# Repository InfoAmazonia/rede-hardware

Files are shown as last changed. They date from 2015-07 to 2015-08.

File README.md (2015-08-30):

# Mãe d'Água - Hardware

An open hardware to monitor water quality in real time. The system will help infer physicochemical properties and variables that differentiate drinkable from contaminated water. Mãe d'Água is part of the project <a href="http://infoamazonia.org/projects/infoamazonia-network/">InfoAmazonia Network</a>.

The device will measure acidity in water by potential of hydrogen (pH), oxidation - reduction potential (ORP), conductivity, temperature and barometric pressure in the water level, which are important factors to consider when assessing water quality for human consumption.

The hardware is modular:
- Module 1 (M1): composed by Arduino Mega, it is responsible for all processing of information captured by the sensors and the entire power supply (connected to an external source).
- Module 2 (M2): Arduino shield (in this repository), designed using Eagle platform, with the barometric pressure sensor and connectors for coupling the pH, ORP, conductivity and water temperature sensors. This way, it is possible to select modules that are appropriate aiming the best cost-benefit ratio of specific desired application.
- Module 3 (M3): responsible for mobile communication (2G), capable of transmitting data by Internet and by SMS to the InfoAmazonia Network internet server. As auxiliary data access strategy, the M2 also features a SD memory card slot.

The complete hardware will capture a reading of each of the sensors per hour, and send them to our remote server, which will provide visualization in an open database.

The development files of the project's hardware/software can be found at:
- Hardware's design: https://github.com/InfoAmazonia/rede-hardware
- Firmware: https://github.com/InfoAmazonia/rede-firmware
- Website for data visualization: https://github.com/InfoAmazonia/rede-site
- SMS backend (to receive data from the equipments and to send alerts to the communities): https://github.com/InfoAmazonia/rede-sms

This hardware is licensed under the <a href="http://www.ohwr.org/attachments/2388/cern_ohl_v_1_2.txt">CERN Open Hardware License Version 1.2.</a>

The EC sensor of this project is based on <a href="http://publiclab.org/notes/donblair/09-30-2014/coqui-bbv1-0">Coqui BBv1.0.</a>

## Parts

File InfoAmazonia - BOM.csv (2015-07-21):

Qty | Value | Device | Package | Parts | Description | MF | MPN | OC_FARNELL | OC_NEWARK | PROD_ID
1 | 100 | R-EU_R0603 | R0603 | R3 | RESISTOR, European symbol
22 | 100nF | C-EUC0603 | C0603 | C1, C6, C9, C10, C11, C13, C14, C15, C16, C17, C18, C20, C21, C22, C24, C25, C27, C29, C31, C33, C35, C37 | CAPACITOR, European symbol
1 | 10100660686 | USD-SOCKETNEW | MICRO-SD-SOCKET-PP | U3 | microSD Socket
3 | 10k | R-EU_R0603 | R0603 | R1, R2, R5 | RESISTOR, European symbol
7 | 10uF | C-EUC0603 | C0603 | C19, C23, C26, C32, C34, C36, C38 | CAPACITOR, European symbol
1 | 1k | R-EU_R0603 | R0603 | R8 | RESISTOR, European symbol
1 | 1uF | C-EUC0603 | C0603 | C30 | CAPACITOR, European symbol
1 | 2.2nF | C-EUC0603 | C0603 | C28 | CAPACITOR, European symbol
1 | 220 | R-EU_R0603 | R0603 | R4 | RESISTOR, European symbol
3 | 220uF | CPOL-EUUD6,3-5,8 | UD-6,3X5,8_NICHICON | C7, C8, C12 | POLARIZED CAPACITOR, European symbol
1 | 2k2 | R-EU_R0603 | R0603 | R11 | RESISTOR, European symbol
4 | 30k | R-EU_R0603 | R0603 | R7, R12, R13, R15 | RESISTOR, European symbol
3 | 31-5431-10RFX | BNCPTH | BNC | J1, J2, J3 | BNC Connector, Mouser Part# 5227161
2 | 47uF | CPOL-EUSMC_B | SMC_B | C2, C3 | POLARIZED CAPACITOR, European symbol
2 | 47uF | CPOL-EUUD6,3-5,8 | UD-6,3X5,8_NICHICON | C4, C5 | POLARIZED CAPACITOR, European symbol
1 | 4M7 | R-EU_R0603 | R0603 | R6 | RESISTOR, European symbol
1 | 5k | RTRIM329W | RTRIM3296W | R10 | Trimm resistor
3 | 74HC4053D | 4053D | SO16 | IC6, IC7, IC8 | Triple 2-channel ANALOG MULTIPLEXER
2 | 75k | R-EU_R0603 | R0603 | R9, R14 | RESISTOR, European symbol
4 | 89400-0420 | M04JST-PTH-VERT | JST-4-PTH-VERT | JP1, JP2, JP3, JP4 | Header 4
1 | ADAFRUIT FONA | ADAFRUIT_FONA | ADAFRUIT_FONA | IC1
1 | ALS-PT19 | LIGHTSENSORALS | ALS-PT19 | U4 | Ambient Light Sensor |  |  |  |  | IC-11836
1 | ARDUINO-MEGAPRO | ARDUINO-MEGAPRO | ARDUINO_MEGA_2560 | U1 | Arduino Mega board footprint
1 | CA3140AM Z | AMPOP | SO8 | IC12 | High Performance Video Op Amp | ALTERA CORPORATION | AD811JRZ | 9426485 | 82H2980
1 | CD4050BD | 4050D | SO16 | IC5 | Hex non-inverting BUFFER
1 | HEF4051BT | 4051D | SO16 | IC3 | 8-channel ANALOG MULTIPLEXER
6 | INFO-AMAZONIA-MODULE | INFO-AMAZONIA-MODULE | INFO-AMAZONIA-MODULE | MD1, MD2, MD3, MD4, MD5, MD6
1 | LM2662 | LM2662 | SO8 | IC2
1 | MIC29302AWD | MIC29XXX | TO252-5 | IC4
1 | MPL3115A2 | MPL3115A2LGA8 | LGA8 | U2 | Altimeter/Pressure Sensor, I2C, 1.95V-3.6V supply, 50 to 110kPa |  |  |  |  | IC-10869
1 | NE555 | NE555 | SO8 | IC11 | General purpose bipolar Timer
1 | SHT20 | SHT2X | SHT2X | IC9
1 | TL032C | AMPOP_2R | SO8 | IC10 | Dual Precision, Low Cost, High Speed BiFET Op Amp | ALTERA CORPORATION | AD712KRZ | 1263975 | 59K4556
1 | TL081BCDG4 | AMPOP | SO8 | IC13 | High Performance Video Op Amp | ALTERA CORPORATION | AD811JRZ | 9426485 | 82H2980

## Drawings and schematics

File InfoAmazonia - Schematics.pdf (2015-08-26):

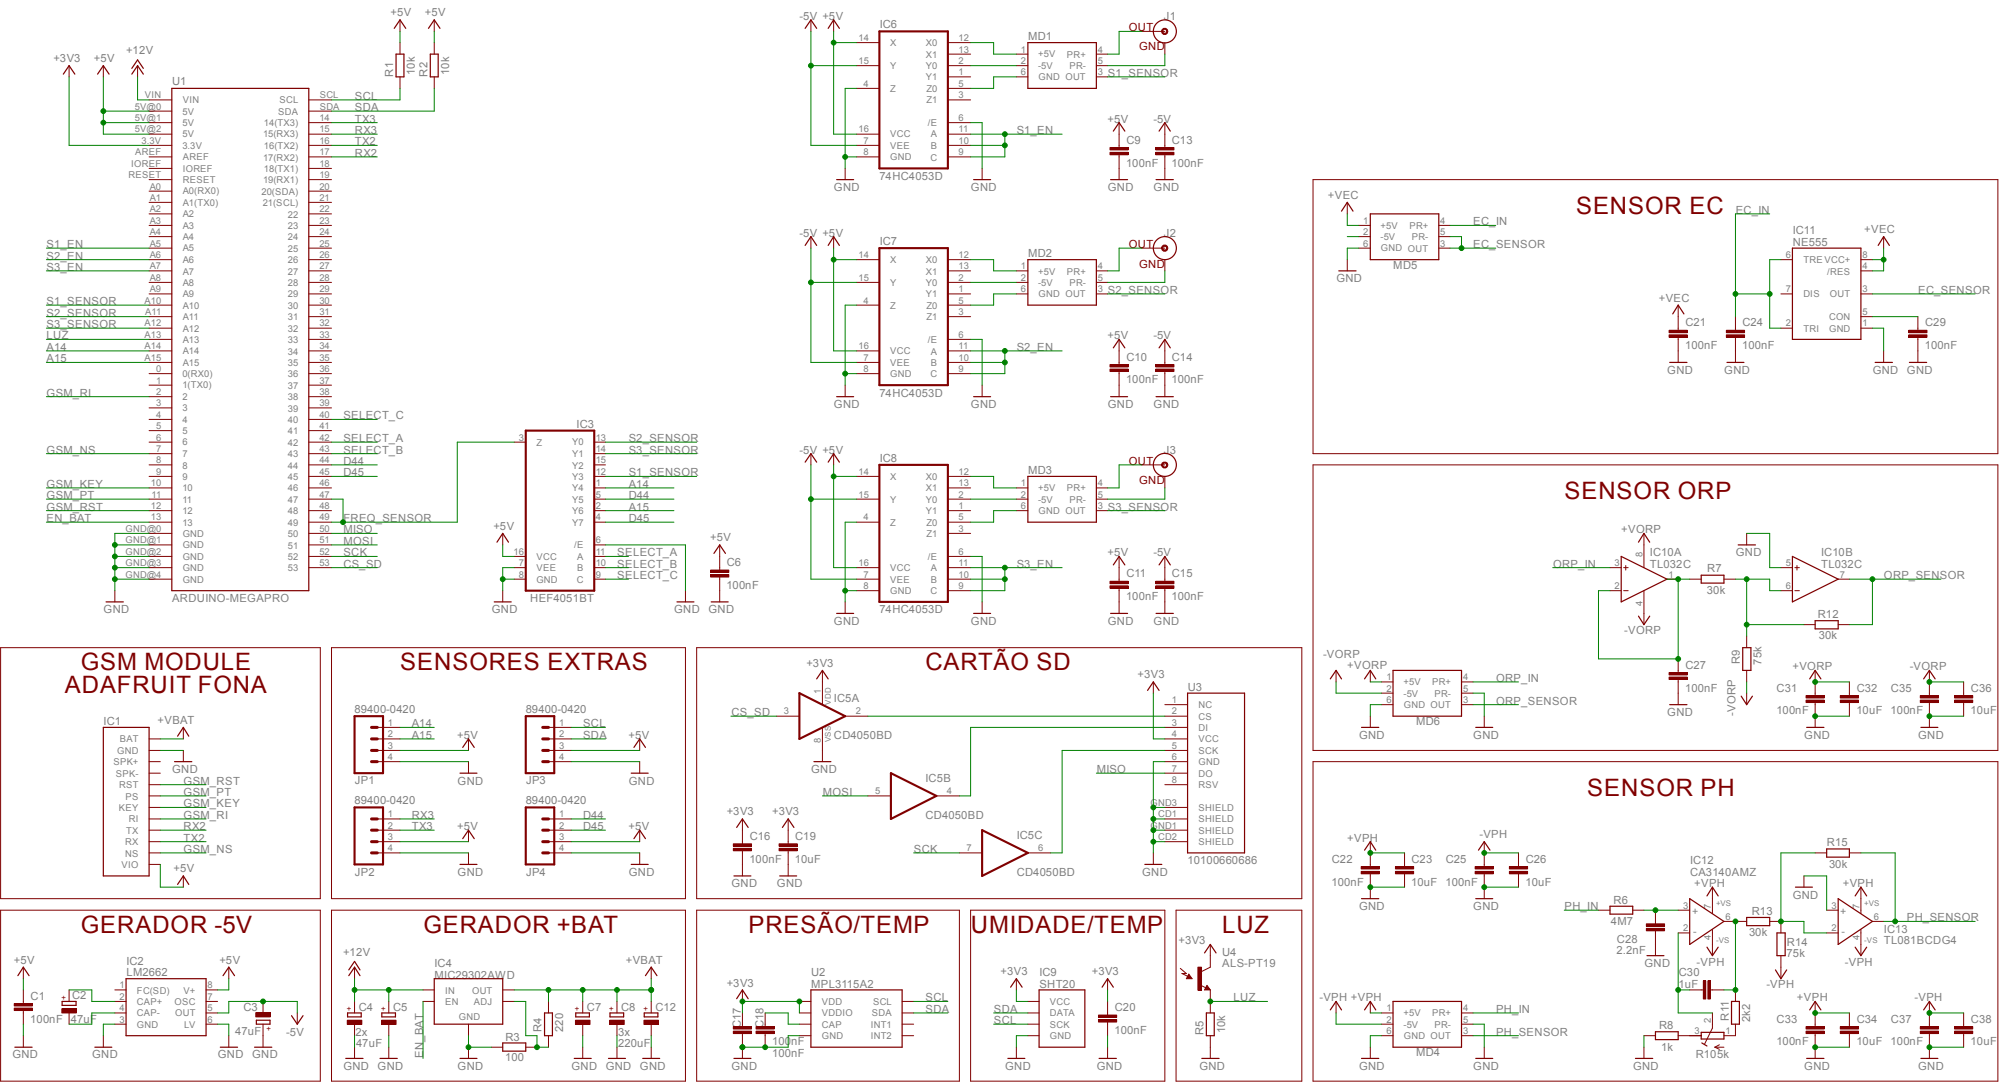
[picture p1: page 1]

5V 5V@1 | TX3
5V 5V@2 | RX3

GND GND@1 | MOSI
GND GND@2 | SCK

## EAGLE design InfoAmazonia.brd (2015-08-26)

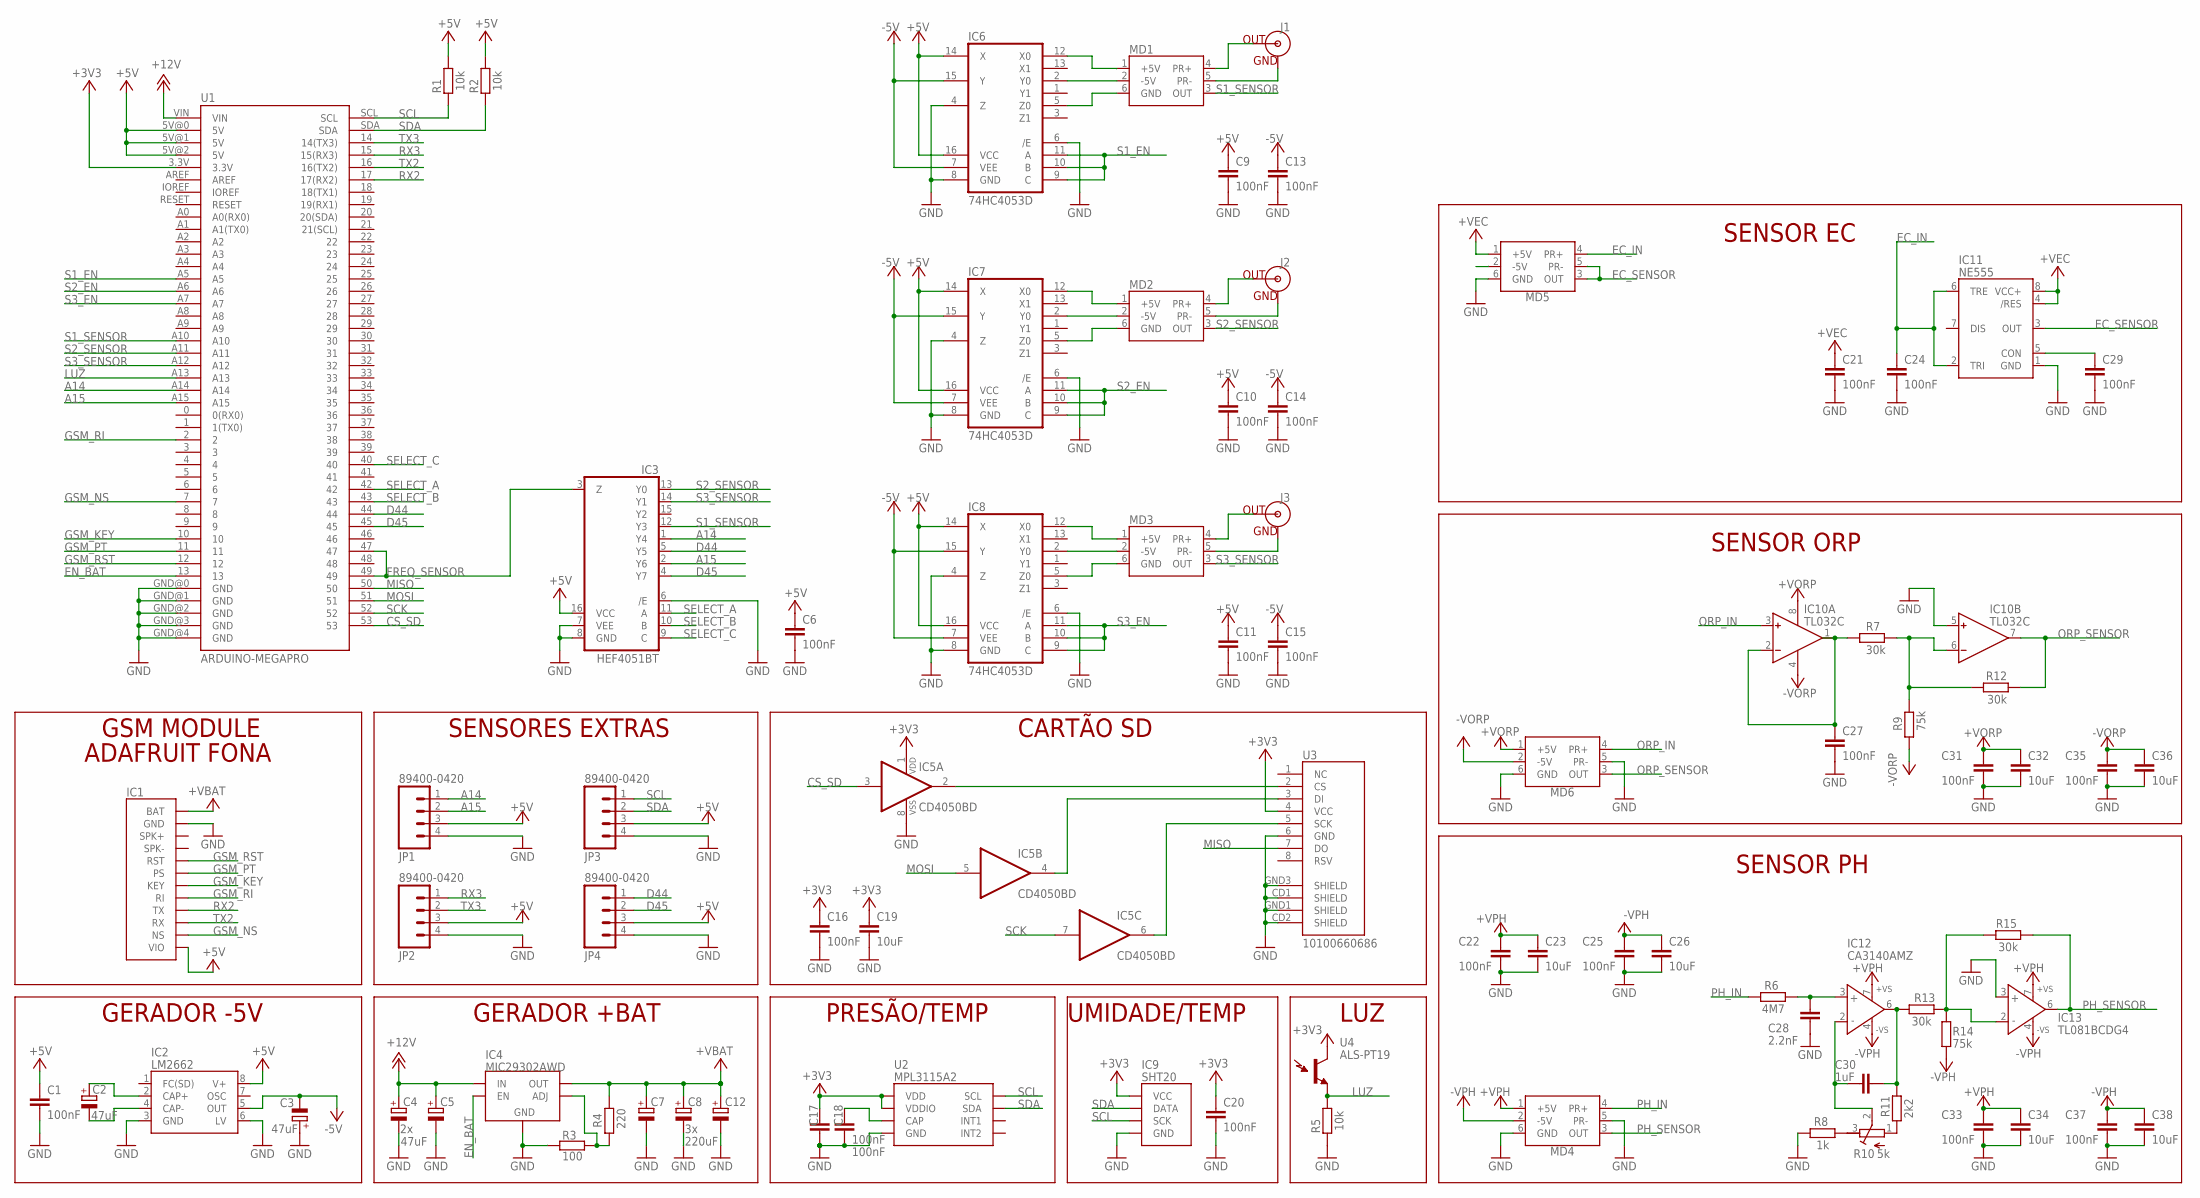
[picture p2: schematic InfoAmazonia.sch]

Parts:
C1, C6, C9, C10, C11, C13, C14, C15, C16, C17, C18, C20, C21, C22, C24, C25, C27, C29, C31, C33, C35, C37: 100nF; C0603
C2, C3: 47uF; SMC_B
C4, C5: 47uF; UD-6,3X5,8_NICHICON
C7, C8, C12: 220uF; UD-6,3X5,8_NICHICON
C19, C23, C26, C32, C34, C36, C38: 10uF; C0603
C28: 2.2nF; C0603
C30: 1uF; C0603
IC1: ADAFRUIT FONA; ADAFRUIT_FONA
IC2: LM2662; SO8
IC3: HEF4051BT; SO16
IC4: MIC29302AWD; TO252-5
IC5: CD4050BD; SO16
IC6, IC7, IC8: 74HC4053D; SO16
IC9: SHT20; SHT2X
IC10: TL032C; SO8
IC11: NE555; SO8
IC12: CA3140AMZ; SO8
IC13: TL081BCDG4; SO8
J1, J2, J3: 31-5431-10RFX; BNC
JP1, JP2, JP3, JP4: 89400-0420; JST-4-PTH-VERT
MD1, MD2, MD3, MD4, MD5, MD6: INFO-AMAZONIA-MODULE
R1, R2, R5: 10k; R0603
R3: 100; R0603
R4: 220; R0603
R6: 4M7; R0603
R7, R12, R13, R15: 30k; R0603
R8: 1k; R0603
R9, R14: 75k; R0603
R10: 5k; RTRIM3296W
R11: 2k2; R0603
U1: ARDUINO-MEGAPRO; ARDUINO_MEGA_2560
U2: MPL3115A2; LGA8
U3: 10100660686; MICRO-SD-SOCKET-PP
U4: ALS-PT19

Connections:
+3V3: C16.1, C17.1, C19.1, C20.1, IC5.1 (VDD), IC9.5 (VCC), U1.3.3V, U2.1 (VDD), U2.4 (VDDIO), U3.4 (VCC), U4.C (C1)
+5V: C1.1, C6.1, C9.1, C10.1, C11.1, IC1.12 (VIO), IC2.8 (V+), IC3.16 (VCC), IC6.14 (X), IC6.16 (VCC), IC7.14 (X), IC7.16 (VCC), IC8.14 (X), IC8.16 (VCC), JP1.3, JP2.3, JP3.3, JP4.3, R1.2, R2.2, U1.5V@0 (5V), U1.5V@1 (5V), U1.5V@2 (5V)
+12V: C4.+, C5.+, IC4.2 (IN), U1.VIN
+VBAT: C7.+, C8.+, C12.+, IC1.1 (BAT), IC4.4 (OUT), R4.1
+VEC: C21.1, IC11.4 (/RES), IC11.8 (VCC+), MD5.1 (+5V)
+VORP: C31.1, C32.1, IC10.8 (V+), MD6.1 (+5V)
+VPH: C22.1, C23.1, C33.1, C34.1, IC12.7 (+VS), IC13.7 (+VS), MD4.1 (+5V)
-5V: C3.-, C13.1, C14.1, C15.1, IC2.5 (OUT), IC6.7 (VEE), IC6.15 (Y), IC7.7 (VEE), IC7.15 (Y), IC8.7 (VEE), IC8.15 (Y)
-VORP: C35.1, C36.1, IC10.4 (V-), MD6.2 (-5V), R9.2
-VPH: C25.1, C26.1, C37.1, C38.1, IC12.4 (-VS), IC13.4 (-VS), MD4.2 (-5V), R14.2
A14: IC3.1 (Y4), JP1.1, U1.A14
A15: IC3.2 (Y6), JP1.2, U1.A15
CS_SD: IC5.3 (I), U1.53
D44: IC3.5 (Y5), JP4.1, U1.44
D45: IC3.4 (Y7), JP4.2, U1.45
EC_IN: C24.1, IC11.2 (TRI), IC11.6 (TRE), MD5.4 (PR+)
EC_SENSOR: IC11.3 (OUT), MD5.3 (OUT), MD5.5 (PR-)
EN_BAT: IC4.1 (EN), U1.13
FC(SD): IC2.1 (FC(SD))
FREQ_SENSOR: IC3.3 (Z), U1.47, U1.49
GND: C1.2, C3.+, C4.-, C5.-, C6.2, C7.-, C8.-, C9.2, C10.2, C11.2, C12.-, C13.2, C14.2, C15.2, C16.2, C17.2, C18.2, C19.2, C20.2, C21.2, C22.2, C23.2, C24.2, C25.2, C26.2, C27.2, C28.2, C29.2, C31.2, C32.2, C33.2, C34.2, C35.2, C36.2, C37.2, C38.2, IC1.2 (GND), IC1.K1 (GND), IC1.K2 (GND), IC2.3 (GND), IC2.6 (LV), IC3.6 (/E), IC3.7 (VEE), IC3.8 (GND), IC4.3 (GND), IC4.6 (GND), IC5.8 (VSS), IC6.4 (Z), IC6.6 (/E), IC6.8 (GND), IC7.4 (Z), IC7.6 (/E), IC7.8 (GND), IC8.4 (Z), IC8.6 (/E), IC8.8 (GND), IC9.2 (GND), IC9.7 (GND), IC10.5 (IN+), IC11.1 (GND), IC13.3 (IN+), JP1.4, JP2.4, JP3.4, JP4.4, MD4.5 (PR-), MD4.6 (GND), MD5.6 (GND), MD6.5 (PR-), MD6.6 (GND), R3.1, R5.1, R8.2, U1.GND@0 (GND), U1.GND@1 (GND), U1.GND@2 (GND), U1.GND@3 (GND), U1.GND@4 (GND), U2.3 (GND), U3.6 (GND), U3.CD1 (SHIELD), U3.CD2 (SHIELD), U3.GND1 (SHIELD), U3.GND3 (SHIELD)
GSM_KEY: IC1.7 (KEY), U1.10
GSM_NS: IC1.11 (NS), U1.7
GSM_PT: IC1.6 (PS), U1.11
GSM_RI: IC1.8 (RI), U1.2
GSM_RST: IC1.5 (RST), U1.12
LUZ: R5.2, U1.A13, U4.E (E1)
MISO: U1.50, U3.7 (DO)
MOSI: IC5.5 (I), U1.51
unnamed: J1.GND, MD1.5 (PR-)
unnamed: C28.1, IC12.3 (IN+), R6.2
unnamed: C30.1, IC12.2 (IN-), R10.2 (S)
unnamed: C30.2, IC12.6 (OUT), R11.2, R13.2
unnamed: IC13.2 (IN-), R13.1, R14.1, R15.1
unnamed: R8.1, R10.3 (E)
unnamed: C18.1, U2.2 (CAP)
unnamed: R10.1 (A), R11.1
unnamed: J1.S (OUT), MD1.4 (PR+)
unnamed: C29.1, IC11.5 (CON)
unnamed: J2.GND, MD2.5 (PR-)
unnamed: J2.S (OUT), MD2.4 (PR+)
unnamed: J3.GND, MD3.5 (PR-)
unnamed: C2.-, IC2.4 (CAP-)
unnamed: C27.1, IC10.1 (OUT), IC10.2 (IN-), R7.2
unnamed: C2.+, IC2.2 (CAP+)
unnamed: IC10.6 (IN-), R7.1, R9.1, R12.1
unnamed: IC4.5 (ADJ), R3.2, R4.2
unnamed: IC5.6 (O), U3.5 (SCK)
unnamed: IC5.4 (O), U3.3 (DI)
unnamed: IC5.2 (O), U3.2 (CS)
unnamed: J3.S (OUT), MD3.4 (PR+)
unnamed: IC6.12 (X0), MD1.1 (+5V)
unnamed: IC6.2 (Y0), MD1.2 (-5V)
unnamed: IC6.5 (Z0), MD1.6 (GND)
unnamed: IC7.5 (Z0), MD2.6 (GND)
unnamed: IC7.2 (Y0), MD2.2 (-5V)
unnamed: IC7.12 (X0), MD2.1 (+5V)
unnamed: IC8.12 (X0), MD3.1 (+5V)
unnamed: IC8.2 (Y0), MD3.2 (-5V)
unnamed: IC8.5 (Z0), MD3.6 (GND)
ORP_IN: IC10.3 (IN+), MD6.4 (PR+)
ORP_SENSOR: IC10.7 (OUT), MD6.3 (OUT), R12.2
PH_IN: MD4.4 (PR+), R6.1
PH_SENSOR: IC13.6 (OUT), MD4.3 (OUT), R15.2
RX2: IC1.9 (TX), U1.17 (17(RX2))
RX3: JP2.1, U1.15 (15(RX3))
S1_EN: IC6.9 (C), IC6.10 (B), IC6.11 (A), U1.A5
S1_SENSOR: IC3.12 (Y3), MD1.3 (OUT), U1.A10
S2_EN: IC7.9 (C), IC7.10 (B), IC7.11 (A), U1.A6
S2_SENSOR: IC3.13 (Y0), MD2.3 (OUT), U1.A11
S3_EN: IC8.9 (C), IC8.10 (B), IC8.11 (A), U1.A7
S3_SENSOR: IC3.14 (Y1), MD3.3 (OUT), U1.A12
SCK: IC5.7 (I), U1.52
SCL: IC9.6 (SCK), JP3.1, R1.1, U1.SCL, U2.8 (SCL)
SDA: IC9.1 (DATA), JP3.2, R2.1, U1.SDA, U2.7 (SDA)
SELECT_A: IC3.11 (A), U1.42
SELECT_B: IC3.10 (B), U1.43
SELECT_C: IC3.9 (C), U1.40
TX2: IC1.10 (RX), U1.16 (16(TX2))
TX3: JP2.2, U1.14 (14(TX3))

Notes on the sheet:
SENSOR ORP
SENSOR PH
PRESÃO/TEMP
UMIDADE/TEMP
GERADOR -5V
GERADOR +BAT
LUZ
CARTÃO SD
SENSOR EC
GSM MODULE
ADAFRUIT FONA
SENSORES EXTRAS

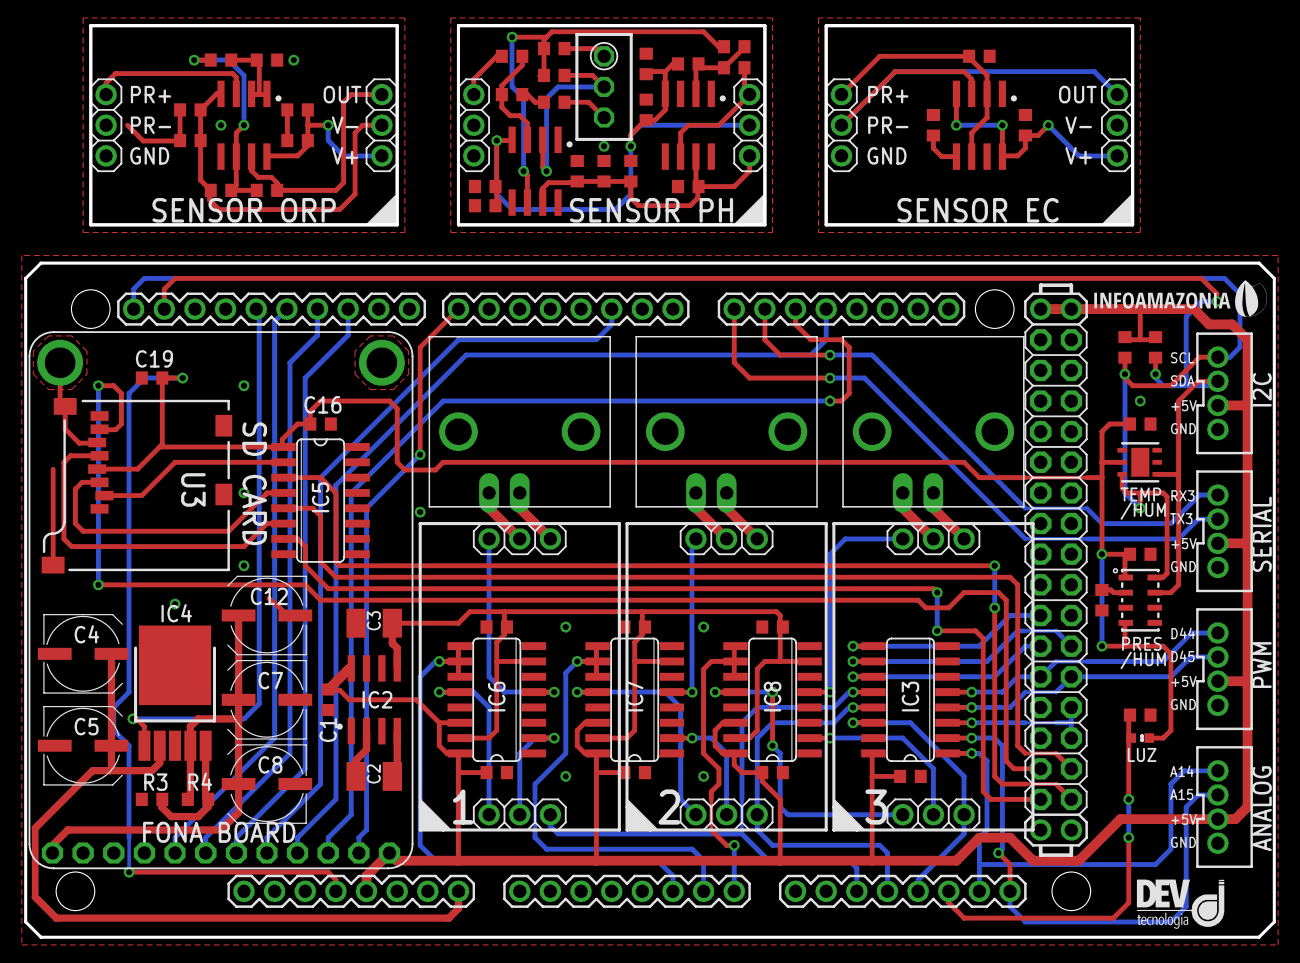
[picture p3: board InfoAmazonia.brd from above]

Board: 2 copper layers, 103.5 x 75.6 mm, 85 parts (0 on the bottom side), 79 nets.

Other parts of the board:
U$1: LOGO-INFO-0.38
U$2: LOGO-DEV-0.9

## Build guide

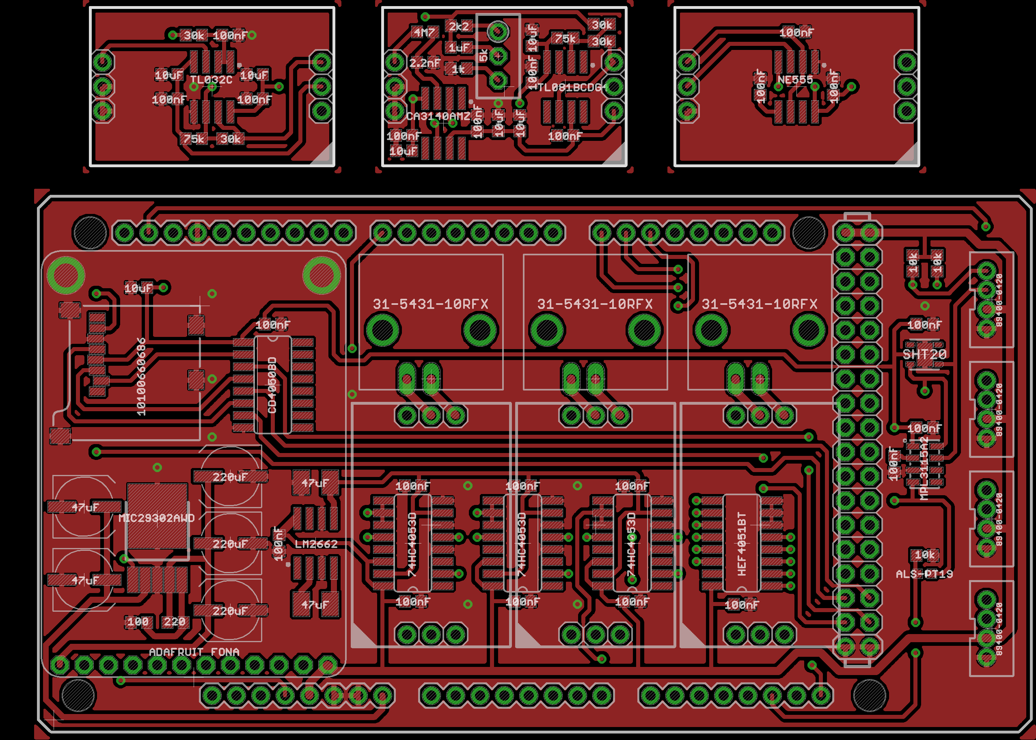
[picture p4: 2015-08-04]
InfoAmazonia - Assembly Drawing.png

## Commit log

2015-04-02 - pHmetro feito
    [InfoAmazonia.sch]
2015-04-08 - Placa criada
    [InfoAmazonia.brd, InfoAmazonia.sch]
2015-04-14 -Acho que não adicionou praticamente nada
    [InfoAmazonia.sch]
2015-04-16 [INFOA-19]
    - Alguns valores de componentes alterados, bom mandado pra avaliação
    [InfoAmazonia.brd, InfoAmazonia.sch]
2015-04-22 - SD adicionado
    [InfoAmazonia.brd, InfoAmazonia.sch]
2015-04-27 - Decidido que sera utilizado o sensor do rifle pra EC
    [InfoAmazonia.brd, InfoAmazonia.sch]
2015-04-28 - Adicionado sensor de EC
    [InfoAmazonia.brd, InfoAmazonia.sch]
2015-04-28 - Terminado o esquematico
    [InfoAmazonia.brd, InfoAmazonia.sch]
2015-04-28 - Acho que mudei uns detlhes cosmeticos
    [InfoAmazonia.sch]
2015-05-08 [INFOA-26]
    - Mudanças de conector JST PH
    [InfoAmazonia.brd, InfoAmazonia.sch]
2015-05-14 [INFOA-26]
    - Placa roteada pelo Anderson
    [InfoAmazonia.brd]
2015-05-29 - Mudanças cosmeticas na parte dos sensores
    [InfoAmazonia.brd]
2015-05-29 - Mudancas no silkscreen da placa
    [InfoAmazonia.brd, InfoAmazonia.sch]
2015-06-04 - Ajustes depois do prototipo
    [InfoAmazonia.brd, InfoAmazonia.sch]
2015-06-08 - Alteracao nos modulos externos. Agora devem caber em uma protoboard.
    [InfoAmazonia.brd]
2015-06-09 - Mudanças bem minimas (Valores de capacitor por exemplo)
    [InfoAmazonia.brd, InfoAmazonia.sch]
2015-06-10 - Agora os modulos tem tamanho definido via componente nas bibliotecas
    [InfoAmazonia.brd, InfoAmazonia.sch]
2015-06-11 - Mudanca no pino rx/tx do fona
    [InfoAmazonia.brd, InfoAmazonia.sch]
2015-06-17 - Commit antes de tentar transferir os sensores de temp/luz/presao para a lateral direita
    [InfoAmazonia.brd, InfoAmazonia.sch]
2015-06-23 - Coloquei os sensores pro lado
    [InfoAmazonia.brd, InfoAmazonia.sch]
2015-06-27 - Roteado os sensores do lado
    [InfoAmazonia.brd, InfoAmazonia.sch]
2015-07-15 - Mudanca de posicao de alguns componentes basicos
    [InfoAmazonia.brd]
2015-07-17 - Adicionado o controlador de tensões, falta rotear
    [InfoAmazonia.brd, InfoAmazonia.sch]
2015-07-18 - Faltando somente distribuicao do +3V3 e decidir se a interrupcao do sensor de pressao fica
    [InfoAmazonia.brd, InfoAmazonia.sch]
2015-07-20 - Roteamento terminado, pendendo revisão
    [InfoAmazonia.brd, InfoAmazonia.sch]
2015-07-20 - Adicionado tented vias
    [InfoAmazonia.brd]
2015-07-20 - Versao enviada para cotacao
    [InfoAmazonia.brd]
2015-07-20 - Mudancas cosmeticas
    [InfoAmazonia.brd]
2015-07-20 - Versao enviada para producao
    [InfoAmazonia.brd, InfoAmazonia.sch]
2015-07-20 - Versao enviada para fabricacao
    [InfoAmazonia.brd]
2015-07-21 - Mudado o codigo de alguns componentes para bater com o BOM
    [InfoAmazonia - BOM.csv, InfoAmazonia.brd, InfoAmazonia.sch]
2015-08-04 - Adicionado o assembly drawing
    [InfoAmazonia.brd, InfoAmazonia.sch]
2015-08-26 - Adicionado o logo da infoamazonia nas placas
    [InfoAmazonia.brd]
